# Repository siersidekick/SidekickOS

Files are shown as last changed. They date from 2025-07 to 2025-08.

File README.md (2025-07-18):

# SidekickOS - Open Source Smart Glasses

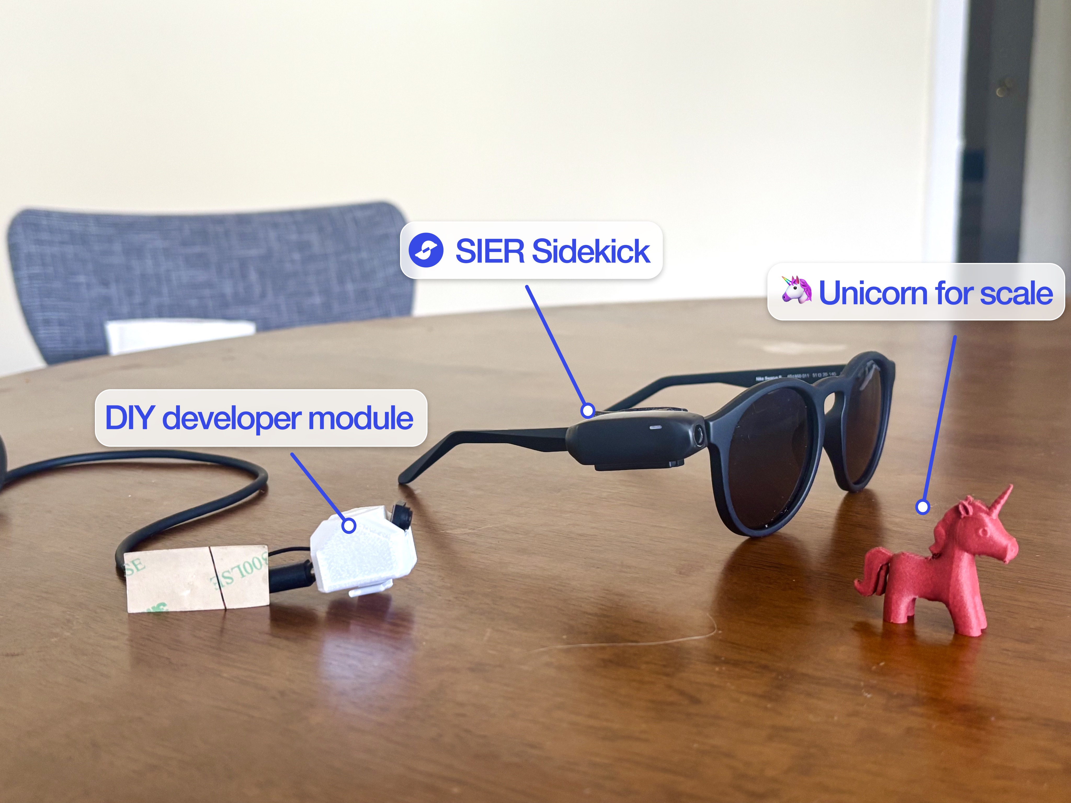
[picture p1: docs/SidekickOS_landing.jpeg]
SidekickOS Landing


An open-source implementation of smart glasses functionality, inspired by the [SIER Sidekick](https://siertech.com). Transform any glasses into smart glasses with camera capture, audio streaming, and AI assistance capabilities.






## 🎯 **What is SidekickOS?**

SidekickOS is an open-source smart glasses platform that provides:

- **📷 High-Resolution Camera Capture** - Up to 1600x1200 native
- **🎤 Audio Streaming** - G.711 μ-law encoded audio over BLE (Work in Progress)
- **📱 Multi-Platform Clients** - Python API and Web browser interface
- **⚡ Ultra-Performance** - Optimized BLE 5.0 with 517-byte MTU and Data Length Extension
- **🔧 Modular Design** - Separate firmware and client components
- **🌍 Cross-Platform** - Works on Mac, Windows, Linux, and mobile apps (React Native in development)

### **Developed with SIER Technologies**

This project is developed in collaboration with [SIER Technologies](https://siertech.com), makers of the Sidekick smart glasses:
- Turn any glasses into smart glasses
- Capture life with high-quality camera
- Voice-activated AI assistance (through client integration)
- Live streaming capabilities (through client apps)
- Hands-free operation

## 🚀 **Quick Start**

### **1. Hardware Setup**

**Required Hardware:**
- XIAO ESP32S3 Sense (with camera and microphone)
- USB-C cable for programming

**3D Printable Hardware:**
- **CAD Model**: [`hardware/SidekickOS-ESP32S3-v1.step`](hardware/SidekickOS-ESP32S3-v1.step) - Full 3D model for modifications
- **3D Print Files**: 
  - [`hardware/SidekickOS-ESP32S3-v1-print.stl`](hardware/SidekickOS-ESP32S3-v1-print.stl) - STL format
  - [`hardware/SidekickOS-ESP32S3-v1-print.3mf`](hardware/SidekickOS-ESP32S3-v1-print.3mf) - 3MF format (recommended)

**Hardware Renders:**
| Front View | Back View |
|---|---|
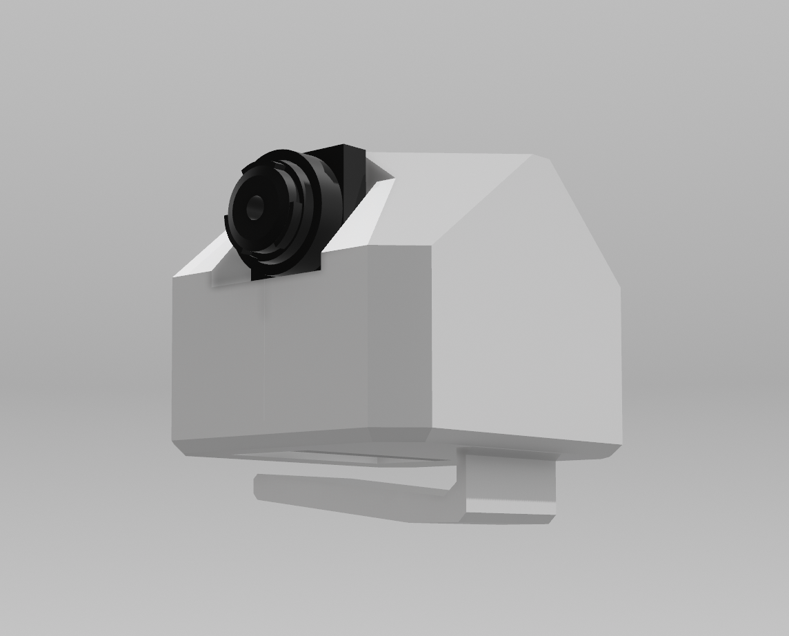
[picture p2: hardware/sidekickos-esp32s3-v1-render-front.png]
Front Render
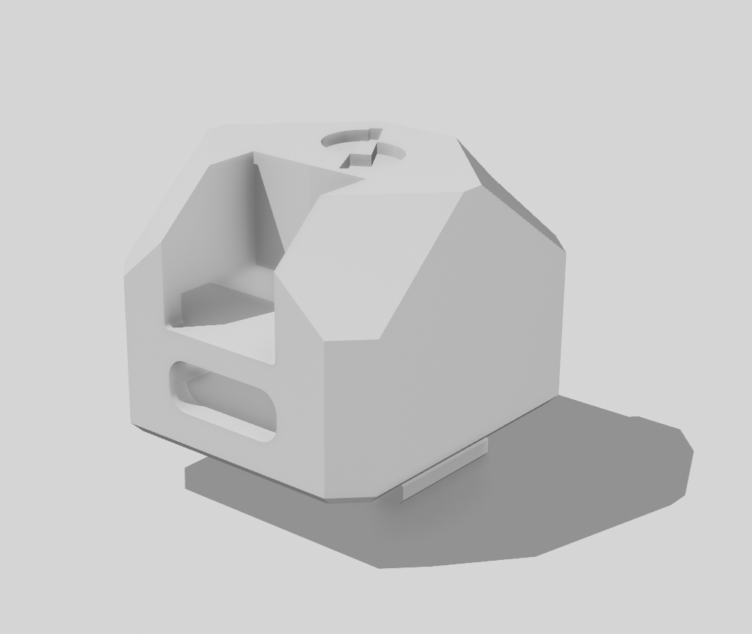
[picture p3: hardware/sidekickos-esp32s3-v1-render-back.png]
Back Render
|  |  |

**Note:** 3D printable mounting solution now available! See [`docs/hardware.md`](docs/hardware.md) for complete assembly instructions.

### **2. Firmware Installation**

```bash
# Clone the repository
git clone https://github.com/siersidekick/SidekickOS.git
cd sidekickos/firmware

# Install ESP-IDF (if not already installed)
# Follow: https://docs.espressif.com/projects/esp-idf/en/latest/esp32/get-started/

# Build and flash firmware
idf.py build
idf.py flash monitor
```

### **3. Client Setup**

**Python Client:**
```bash
cd sidekickos-client
pip install -e .
python demos/example_camera_usage.py
```

**Web Client:**
```bash
# Simply open demos/sidekickos-web-client.html in a modern desktop browser
# Requires Web Bluetooth API support (Chrome/Edge on desktop only)
# Note: iOS Safari and mobile browsers do not support Web Bluetooth
```

## 📱 **Client Applications**

### **Python Client (`sidekickos-client/`)**

**Features:**
- Full camera control and streaming
- High-resolution image capture (up to 1920x1080)
- Audio streaming and processing (Work in Progress)
- Performance monitoring
- Cross-platform (Mac, Windows, Linux)

**Usage:**
```python
from sidekickos import ESP32Camera

camera = ESP32Camera()
await camera.connect()
image = await camera.capture_image()
image.save("photo.jpg")
```

### **Web Client (`sidekickos-client/sidekickos-web-client.html`)**

**Features:**
- Browser-based interface (no installation required)
- Real-time camera streaming
- Audio streaming with Web Audio API (Work in Progress)
- Performance monitoring dashboard
- Desktop compatible (Chrome/Edge only, no iOS/mobile browser support)

**Usage:**
1. Open `sidekickos-client/sidekickos-web-client.html` in Chrome/Edge (desktop only)
2. Click "Connect to Camera"
3. Start capturing photos or streaming video

**Mobile App (React Native):**
- iOS and Android app in development
- Will provide full mobile BLE support
- Expected release: next few months

## 🔧 **Technical Specifications**

### **ESP32S3 Firmware**
- **Camera**: OV2640 sensor, JPEG compression
- **Audio**: PDM microphone, G.711 μ-law encoding
- **Connectivity**: BLE 5.0 with Data Length Extension
- **Performance**: 300+ kbps bandwidth, 30 FPS capability
- **Resolutions**: 96x96 to 1600x1200 native

### **BLE Protocol**
- **Service UUID**: `12345678-1234-1234-1234-123456789abc`
- **MTU**: Up to 517 bytes (BLE 5.0 DLE)
- **Chunk Size**: 510 bytes optimized
- **Audio**: 8kHz, 16-bit PCM → G.711 μ-law
- **Commands**: Quality, resolution, streaming control

### **Performance Metrics**
- **Image Transfer**: 200-400 kbps
- **Audio Streaming**: 12.8 kbps (Work in Progress)
- **Latency**: 1-3 seconds per frame
- **Range**: 10-30 meters
- **Battery Life**: Several hours (depends on usage and hardware configuration)

## 🎮 **Usage Examples**

### **Basic Photo Capture**
```python
# Python
import asyncio
from sidekickos import ESP32Camera

async def take_photo():
    camera = ESP32Camera()
    await camera.connect()
    
    # Set high quality
    await camera.set_quality(10)
    await camera.set_resolution(8)  # VGA
    
    # Capture image
    image = await camera.capture_image()
    image.save("my_photo.jpg")
    
    await camera.disconnect()

asyncio.run(take_photo())
```

### **Live Streaming**
```python
# Python streaming
def frame_callback(frame):
    print(f"Frame {frame.frame_number}: {frame.size} bytes")
    frame.save(f"frame_{frame.frame_number:04d}.jpg")

await camera.start_streaming(frame_callback, interval=0.5)
await asyncio.sleep(10)  # Stream for 10 seconds
await camera.stop_streaming()
```

### **🐕 Smart Dog Detection Demo**
```bash
cd sidekickos-client
pip install -e .
python demos/dog_detection/simple_dog_detector.py
```

## 🛠️ **Development**

### **Firmware Development**
```bash
cd firmware
idf.py menuconfig  # Configure project
idf.py build       # Build firmware
idf.py flash       # Flash to device
idf.py monitor     # View serial output
```

### **Client Development**
```bash
cd sidekickos-client
pip install -e .   # Install in development mode
python -m pytest   # Run tests (if available)
```

### **Adding New Features**

**Firmware Side:**
1. Add new BLE characteristics in `main/main.c`
2. Implement command handlers
3. Update protocol documentation

**Client Side:**
1. Extend `ESP32Camera` class in `sidekickos/__init__.py`
2. Add new methods and callbacks
3. Update examples and documentation

## 📊 **Performance Optimization**

### **For Maximum Quality**
- Use VGA (640x480) or higher resolution
- Set quality to 4-10 (lower = better)
- Use Python client for post-processing
- Enable image enhancement and upscaling

### **For Maximum Speed**
- Use QVGA (320x240) resolution
- Set quality to 25-30
- Use 1-2 second frame intervals
- Use Web client for real-time viewing

### **For Battery Life**
- Reduce frame rate (5+ second intervals)
- Lower resolution (QVGA or below)
- Disable audio streaming when not needed
- Use deep sleep between captures

## 🤝 **Contributing**

We welcome contributions! Please see [CONTRIBUTING.md](CONTRIBUTING.md) for guidelines.

**Areas for Contribution:**
- AI integration (ChatGPT, local models)
- Computer vision demos (expand beyond dog detection)
- React Native mobile app development
- Audio streaming improvements
- Performance optimizations
- Documentation improvements

## 🤖 **AI-Powered Demos**

### **🐕 Dog Detection Demo**
```bash
cd sidekickos-client
pip install -e .
python demos/dog_detection/simple_dog_detector.py
```

Detects dogs and saves photos to "cute dogs" folder.

📹 **[Watch Demo Video](https://drive.google.com/file/d/1LnD9ZVXxRB4CjpYO92vVTl6aJtVk8wdE/view?usp=sharing)** - See dog detection in action!

## 📄 **License**

This project is licensed under the MIT License - see the [LICENSE](LICENSE) file for details.

## 🙏 **Acknowledgments**

- Developed in collaboration with [SIER Technologies](https://siertech.com), makers of the Sidekick smart glasses
- Built on ESP-IDF framework and ESP32S3 platform
- Uses Seeed Studio XIAO ESP32S3 Sense hardware
- Community contributions and feedback

## 📚 **Documentation**

Comprehensive documentation is available in the `docs/` directory:

- **[📖 Documentation Index](docs/index.md)** - Complete documentation navigation
- **[Python Library Guide](docs/python-library.md)** - Complete Python client documentation
- **[Demo Scripts](docs/demos.md)** - Guide to all demo applications
- **[Firmware Guide](docs/firmware.md)** - ESP32S3 firmware documentation
- **[Hardware Setup](docs/hardware.md)** - Hardware compatibility and setup
- **[Contributing](CONTRIBUTING.md)** - Guidelines for contributors

## 📞 **Support**

- **Issues**: Open a GitHub issue for bugs or feature requests
- **Discussions**: Use GitHub Discussions for questions and ideas
- **Documentation**: See links above for detailed guides

## 🔮 **Roadmap**

**Current (v1.0):**
- ✅ Basic camera streaming
- ✅ Python and Web clients (desktop)
- ✅ High-resolution capture
- ✅ Performance optimization
- 🔄 Audio streaming (Work in Progress)

**Planned (v1.1):**
- 🔄 React Native mobile app (iOS/Android)
- 🔄 Complete audio streaming implementation
- 🔄 AI integration (ChatGPT, local models)
- 🔄 Voice activation ("Hey Sidekick")

**Future (v2.0):**
- 🔄 Live streaming to social platforms
- 🔄 Real-time object recognition
- 🔄 Augmented reality overlays
- 🔄 Advanced AI assistant features

---

**Turn any glasses into smart glasses with SidekickOS! 🤓✨**

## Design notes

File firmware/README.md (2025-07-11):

# SidekickOS ESP32S3 Firmware

This directory contains the ESP32S3 firmware for the SidekickOS smart glasses project.

## 🚀 **Quick Start**

```bash
# Install ESP-IDF (if not already installed)
# Follow: https://docs.espressif.com/projects/esp-idf/en/latest/esp32/get-started/

# Build and flash
idf.py build
idf.py flash monitor
```

## 📁 **Directory Structure**

```
firmware/
├── main/                   # Main application code
│   ├── main.c             # Primary firmware implementation
│   ├── CMakeLists.txt     # Main component build config
│   └── idf_component.yml  # Component dependencies
├── components/             # Custom components
│   └── posix_stub/        # POSIX compatibility layer
├── managed_components/     # ESP component dependencies
│   ├── espressif__esp32-camera/    # Camera driver
│   └── espressif__esp_h264/        # H.264 codec (future use)
├── CMakeLists.txt         # Project build configuration
├── dependencies.lock      # Dependency lock file
├── partitions.csv         # Flash partition table
├── sdkconfig*             # Build configuration files
└── README.md             # This file
```

## 🔧 **Features**

- **Camera**: OV2640 sensor with JPEG compression
- **Audio**: PDM microphone with G.711 μ-law encoding
- **BLE**: Optimized BLE 5.0 with 517-byte MTU
- **Performance**: 240MHz CPU, PSRAM optimization
- **Streaming**: Real-time image and audio streaming

## 📋 **Requirements**

- **Hardware**: XIAO ESP32S3 Sense
- **ESP-IDF**: Version 5.0 or later
- **Python**: Version 3.6 or later (for ESP-IDF)

## 🔨 **Build Instructions**

### **1. Setup ESP-IDF**
```bash
# Clone ESP-IDF
git clone -b v5.0 --recursive https://github.com/espressif/esp-idf.git
cd esp-idf
./install.sh
source export.sh
```

### **2. Build Firmware**
```bash
cd sidekickos/firmware

# Configure (optional - defaults are optimized)
idf.py menuconfig

# Build
idf.py build

# Flash and monitor
idf.py flash monitor
```

## ⚙️ **Configuration**

Key configuration options:

- **Target**: ESP32-S3
- **CPU Frequency**: 240MHz
- **Flash Size**: 8MB
- **PSRAM**: Enabled (Octal, 80MHz)
- **BLE**: Enabled with Data Length Extension
- **Camera**: ESP32-Camera component

## 📊 **Performance**

- **Image Streaming**: 200-400 kbps
- **Audio Streaming**: 12.8 kbps
- **Frame Rate**: Up to 30 FPS
- **Latency**: 1-3 seconds per frame
- **Range**: 10-30 meters

## 🔧 **Customization**

See [firmware documentation](../docs/firmware.md) for detailed customization instructions.

## 🐛 **Troubleshooting**

### **Common Issues**

| Problem | Solution |
|---|---|
| Build fails | Ensure ESP-IDF v5.0+ is installed and sourced |
| Camera not working | Check hardware connections, try lower resolution |
| BLE not visible | Verify BLE is enabled in menuconfig |
| Flash errors | Check USB connection, try different cable |

### **Debug Output**

```bash
# Monitor with filtering
idf.py monitor --print_filter="*:I ESP32S3_CAMERA:D"

# Save debug output
idf.py monitor | tee debug.log
```

## 📞 **Support**

- **Documentation**: See [../docs/firmware.md](../docs/firmware.md)
- **Issues**: Open GitHub issue with firmware tag
- **ESP-IDF Help**: [ESP-IDF Documentation](https://docs.espressif.com/projects/esp-idf/)

---

**Part of the SidekickOS open-source smart glasses project 🤓**

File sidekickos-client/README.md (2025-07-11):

# SidekickOS Python Library

This directory contains the SidekickOS Python library for ESP32S3 BLE camera interface.

## Quick Start

```bash
# Install the library
pip install -e .

# Run a demo
python demos/example_camera_usage.py
```

## 📚 Documentation

For complete documentation, please see:

- **[Python Library Guide](../docs/python-library.md)** - Complete API documentation
- **[Demo Scripts Guide](../docs/demos.md)** - Guide to all demo applications
- **[Main Project README](../README.md)** - Project overview and getting started

## Structure

```
sidekickos-client/
├── sidekickos/           # Main Python library
│   └── __init__.py        # ESP32Camera, ImageFrame classes
├── demos/                 # Example scripts
│   ├── example_camera_usage.py
│   └── dog_detection/
├── setup.py               # Installation configuration
└── requirements.txt       # Dependencies
```

## Quick Install & Test

```bash
pip install -e .
python -c "from sidekickos import ESP32Camera; print('✅ Installation successful!')"
```

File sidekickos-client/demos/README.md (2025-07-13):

# SidekickOS Demos

This directory contains various demonstration scripts and examples for the SidekickOS platform.

## 📁 **Available Demos**

### **🤖 Gemini Live Demo** (`gemini_live/`)
A smart glasses demo that integrates the SidekickOS BLE camera with Google's Gemini Live API for real-time computer vision and audio interaction.

**Features:**
- Real-time image capture from SidekickOS camera
- Voice interaction with Gemini AI
- Audio responses describing what the AI sees
- True smart glasses experience

**Setup:** See `gemini_live/GEMINI_DEMO_README.md`

### **🐕 Dog Detection Demo** (`dog_detection/`)
Computer vision demo for detecting dogs in camera feeds.

### **📷 Basic Camera Usage** (`example_camera_usage.py`)
Basic examples showing how to use the SidekickOS camera for image capture and streaming.

## 🚀 **Quick Start**

1. **Install base dependencies:**
   ```bash
   pip install -r requirements.txt
   ```

2. **Choose a demo:**
   - For Gemini Live: `cd gemini_live && python sidekickos_gemini_demo.py`
   - For basic camera: `python example_camera_usage.py`

3. **Make sure your SidekickOS device is powered on and nearby**

## 📋 **Requirements**

- SidekickOS device (powered on and in range)
- Python 3.8+
- Additional requirements per demo (see individual README files)

## 💡 **Creating New Demos**

To add a new demo:

1. Create a new subdirectory: `mkdir your_demo_name/`
2. Add your demo files
3. Include a README.md with setup instructions
4. Update this index file

## 🆘 **Need Help?**

- Check individual demo README files for specific setup instructions
- Ensure your SidekickOS device is properly configured
- Verify all dependencies are installed

---

**Happy coding with SidekickOS!** 🤖👓

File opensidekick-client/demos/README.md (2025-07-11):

# OpenSidekick Demo Scripts

This directory contains demonstration scripts for the OpenSidekick ESP32 camera system.

## Prerequisites

Install the opensidekick library:

```bash
cd ..
pip install -e .
```

Or install dependencies manually:

```bash
cd ..
pip install -r requirements.txt
```

## Demo Scripts

### Camera Examples

**example_camera_usage.py**
Basic camera usage examples: single image capture, video streaming, performance testing, interactive mode.

```bash
python example_camera_usage.py
```

**practical_high_res.py**
High-resolution image capture with intelligent upscaling to 1920x1080.

```bash
python practical_high_res.py
```

**opensidekick-web-client.html**
Web-based camera interface. Open in any web browser and follow instructions to connect.

### Dog Detection

Dog detection demos are in the `dog_detection/` folder:

**dog_detection/simple_dog_detector.py**
Streamlined dog detection. Saves clean images to "cute dogs" folder.

```bash
cd dog_detection
python simple_dog_detector.py
```

**dog_detection/dog_detector_demo.py**
Advanced dog detection with performance monitoring and statistics.

```bash
cd dog_detection
python dog_detector_demo.py
```

## Running Demos

1. Connect your ESP32 camera and make sure it's powered on
2. Navigate to the appropriate directory
3. Run the script

## Troubleshooting

- Import errors: Make sure you're running from the correct directory
- Camera connection issues: Ensure ESP32 is powered and Bluetooth is enabled
- Missing dependencies: Run `pip install -r ../requirements.txt`

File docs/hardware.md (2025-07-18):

# Hardware Guide - SidekickOS

## 🔧 **Required Hardware**

### **Primary Components**

#### **XIAO ESP32S3 Sense**
- **MCU**: ESP32-S3 dual-core processor @ 240MHz
- **Memory**: 8MB PSRAM, 8MB Flash
- **Camera**: OV2640 2MP camera sensor
- **Microphone**: PDM digital microphone
- **Connectivity**: WiFi 802.11 b/g/n, Bluetooth 5.0 BLE
- **Size**: 21×17.5mm (ultra-compact)
- **Power**: USB-C charging, 3.7V battery connector

**Purchase Links:**
- [Seeed Studio Official](https://www.seeedstudio.com/XIAO-ESP32S3-Sense-p-5639.html)
- [Amazon](https://amazon.com/dp/B0C69FFVHH)
- [Adafruit](https://www.adafruit.com/product/5426)

#### **Glasses Frame**
- Any standard eyeglasses frame

#### **3D Printable Mount**
- **📁 Hardware Files**: Available in [`../hardware/`](../hardware/) directory
- **🖨️ 3D Print Ready**: STL and 3MF files included
- **🔧 CAD Model**: STEP file for modifications
- **📸 Visual Reference**: Front and back render images

### **Optional Components**

#### **Battery Pack**
- **Capacity**: 100-500mAh recommended
- **Voltage**: 3.7V Li-Po battery
- **Size**: Small enough to fit in glasses arm or pocket

**Recommended Batteries:**
- Small form factor Li-Po batteries
- Capacity depends on use case and mounting solution

#### **Mounting Hardware**
- Mounting solutions currently in development
- Hardware assembly documentation coming soon

## 🔌 **Wiring and Connections**

**Note**: All pins are pre-configured in the firmware. No external wiring required for basic functionality.

## 🔋 **Power Management**

### **Power Consumption**
- **Idle**: ~50mA
- **Camera Active**: ~150-200mA
- **BLE Streaming**: ~200-250mA
- **Peak Usage**: ~300mA

### **Battery Life Estimates**
Battery life depends on:
- Camera resolution and quality settings
- Frame rate and streaming frequency
- Audio streaming usage (when implemented)
- BLE connection activity

Typical usage with optimized settings: 2-8 hours depending on battery capacity and usage patterns.

### **Power Optimization Tips**
- Use deep sleep between captures
- Reduce frame rate for longer battery life
- Lower camera resolution when possible
- Disable audio streaming when not needed

## 🏗️ **Mechanical Design**

### **3D Printable Mounting Solution**

**Available Hardware Files:**
- **CAD Model**: [`../hardware/SidekickOS-ESP32S3-v1.step`](../hardware/SidekickOS-ESP32S3-v1.step) - Full 3D model (STEP format)
- **3D Print Ready**: 
  - [`../hardware/SidekickOS-ESP32S3-v1-print.stl`](../hardware/SidekickOS-ESP32S3-v1-print.stl) - STL format
  - [`../hardware/SidekickOS-ESP32S3-v1-print.3mf`](../hardware/SidekickOS-ESP32S3-v1-print.3mf) - 3MF format (recommended)

**Hardware Renders:**
| Front View | Back View |
|---|---|
| Front Render | Back Render |

### **Mounting Features**

The SidekickOS ESP32S3 v1 mount includes:

- **Glasses Frame Integration**: Designed to clip onto standard eyeglass frames
- **Secure Camera Positioning**: Optimized positioning for the OV2640 camera sensor
- **ESP32S3 Housing**: Custom fit for the XIAO ESP32S3 Sense module
- **Access Ports**: USB-C port access for programming and charging

### **3D Printing Specifications**

**Recommended Settings:**
- **Layer Height**: 0.2mm
- **Infill**: 20-30%
- **Support**: Required for overhangs
- **Material**: PLA or PETG recommended
- **Print Orientation**: Follow 3MF file orientation

**Print Time**: Approximately 30 minutes to 1 hour depending on settings

## 📐 **Dimensions and Clearances**

### **XIAO ESP32S3 Sense Dimensions**
- Length: 21mm
- Width: 17.8mm
- Height: 15mm (with camera)
- Weight: ~5g

### **Mounting Clearances**
- Camera field of view: 66° diagonal
- Minimum clearance from lens: 15mm
- Recommended mounting height: 5-10mm above frame
- USB-C access: 10mm clearance needed

## 🔧 **Assembly Instructions**

### **3D Printing the Mount**

1. **Download Files**: Get the 3D print files from the [`../hardware/`](../hardware/) directory
2. **Print Settings**: Use the recommended settings above (0.2mm layer height, 20-30% infill)
3. **Support Material**: Enable supports for overhangs
4. **Post-Processing**: Remove supports and sand rough edges if needed

### **Hardware Assembly**

**Step 1: Prepare the ESP32S3**
1. Flash the SidekickOS firmware to your XIAO ESP32S3 Sense
2. Test basic functionality using the serial monitor
3. Verify camera and BLE functionality

**Step 2: Mount Assembly**
1. Carefully insert the ESP32S3 Sense into the 3D printed mount
2. Ensure the camera lens aligns with the mount opening
3. Verify USB-C port accessibility for charging/programming
4. Check that the mount securely holds the device

**Step 3: Glasses Integration**
1. Identify the best mounting position on your glasses frame
2. Clip or attach the mount to the glasses frame
3. Ensure the camera has an unobstructed view
4. Test comfort and stability during movement

**Step 4: Final Testing**
1. Connect via Python or Web client
2. Test camera capture and streaming
3. Verify comfortable fit during extended wear
4. Adjust mounting position if needed

### **Tools Required**
- 3D printer (or access to 3D printing service)
- Basic hand tools for post-processing
- Your favorite glasses frame
- XIAO ESP32S3 Sense module

## 🛡️ **Safety Considerations**

### **Electrical Safety**
- Use proper Li-Po battery handling procedures
- Avoid short circuits
- Monitor battery temperature during charging
- Use appropriate fuses if modifying power circuits

### **Mechanical Safety**
- Ensure secure mounting to prevent device falling
- Avoid sharp edges in 3D printed parts
- Test comfort during extended wear
- Consider impact resistance for active use

### **Privacy and Legal**
- Check local laws regarding recording devices
- Consider privacy implications of camera/microphone
- Add visible indicators when recording
- Respect others' privacy in public spaces

## 🔍 **Troubleshooting**

### **Common Hardware Issues**

| Problem | Possible Cause | Solution |
|---|---|---|
| Camera not working | Loose connection | Check camera ribbon cable |
| Poor image quality | Lens dirty/scratched | Clean lens, check for damage |
| Short battery life | High power consumption | Optimize firmware settings |
| BLE connection issues | Interference | Check for 2.4GHz interference |
| Charging problems | Faulty USB cable | Try different USB-C cable |

### **Hardware Testing**

```bash
# Flash test firmware
cd firmware
idf.py flash monitor

# Check hardware status in serial output
# Look for:
# - Camera initialization success
# - I2S/microphone setup
# - BLE advertising start
# - Memory allocation success
```

## 📞 **Hardware Support**

- **XIAO ESP32S3 Documentation**: [Seeed Studio Wiki](https://wiki.seeedstudio.com/xiao_esp32s3_getting_started/)
- **ESP32S3 Datasheet**: [Espressif Official](https://www.espressif.com/sites/default/files/documentation/esp32-s3_datasheet_en.pdf)
- **Hardware Issues**: Open GitHub issue with hardware tag
- **Community**: Join discussions for hardware modifications and improvements

---

**Ready to build your own smart glasses? Let's get started! 🤓🔧**

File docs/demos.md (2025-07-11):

# SidekickOS Demo Scripts

This directory contains demonstration scripts for the SidekickOS ESP32 camera system.

## Prerequisites

Install the sidekickos library:

```bash
cd ..
pip install -e .
```

Or install dependencies manually:

```bash
cd ..
pip install -r requirements.txt
```

## Demo Scripts

### Camera Examples

**example_camera_usage.py**
Basic camera usage examples: single image capture, video streaming, performance testing, interactive mode.

```bash
python example_camera_usage.py
```

**sidekickos-web-client.html**
Web-based camera interface. Open in any web browser and follow instructions to connect.

### Dog Detection

Dog detection demos are in the `dog_detection/` folder:

**dog_detection/simple_dog_detector.py**
Streamlined dog detection. Saves clean images to "cute dogs" folder.

```bash
cd dog_detection
python simple_dog_detector.py
```

**dog_detection/dog_detector_demo.py**
Advanced dog detection with performance monitoring and statistics.

```bash
cd dog_detection
python dog_detector_demo.py
```

### 🎥 Video Demo

**Dog Detection in Action**
Watch the SidekickOS dog detection demo in action:

📹 **[Dog Detection Demo Video](https://drive.google.com/file/d/1LnD9ZVXxRB4CjpYO92vVTl6aJtVk8wdE/view?usp=sharing)**

This video demonstrates:
- Real-time camera streaming from ESP32S3
- Live dog detection using YOLOv5
- Clean image saving without bounding boxes
- Performance monitoring and statistics
- Bluetooth LE connectivity in action

> **Note**: The video shows the `simple_dog_detector.py` script detecting dogs and automatically saving photos to the "cute dogs" folder.

## Running Demos

1. Connect your ESP32 camera and make sure it's powered on
2. Navigate to the appropriate directory
3. Run the script

## Troubleshooting

- Import errors: Make sure you're running from the correct directory
- Camera connection issues: Ensure ESP32 is powered and Bluetooth is enabled
- Missing dependencies: Run `pip install -r ../requirements.txt`

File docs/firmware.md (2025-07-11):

# Firmware Guide - SidekickOS ESP32S3

## 🚀 **Overview**

The SidekickOS firmware is built on ESP-IDF (Espressif IoT Development Framework) and provides:
- High-performance camera capture and streaming
- Optimized BLE 5.0 communication with 517-byte MTU
- Advanced power management and performance optimization
- Modular architecture for easy customization
(PDM microphone audio with G.711 μ-law encoding is WIP)

## 🏗️ **Architecture**

### **Core Components**

```
SidekickOS Firmware Architecture
┌─────────────────────────────────────────┐
│                main.c                   │
├─────────────────────────────────────────┤
│  ┌─────────────┐  ┌─────────────────┐  │
│  │   Camera    │  │      Audio      │  │
│  │   Module    │  │     Module      │  │
│  │             │  │                 │  │
│  │ • OV2640    │  │ • PDM Mic       │  │
│  │ • JPEG      │  │ • G.711 μ-law   │  │
│  │ • Streaming │  │ • I2S Driver    │  │
│  └─────────────┘  └─────────────────┘  │
├─────────────────────────────────────────┤
│              BLE Stack                  │
│  ┌─────────────────────────────────────┐│
│  │ • Service: Camera Control          ││
│  │ • Characteristics: Image, Audio    ││
│  │ • MTU: 517 bytes (BLE 5.0 DLE)     ││
│  │ • Chunk Protocol: 510-byte packets ││
│  └─────────────────────────────────────┘│
├─────────────────────────────────────────┤
│           Performance Layer             │
│  • CPU: 240MHz locked                  │
│  • Memory: PSRAM optimization          │
│  • Power: Aggressive connection params │
│  • Tasks: Dual-core task distribution  │
└─────────────────────────────────────────┘
```

### **Task Architecture**

| Task | Core | Priority | Stack Size | Function |
|---|---|---|---|---|
| Main Task | 0 | 1 | 8KB | System initialization, watchdog |
| Streaming Task | 1 | 10 | 16KB | Camera capture, image transmission |
| Audio Task | 0 | 9 | 8KB | Microphone capture, audio streaming |
| BLE Stack | 0 | 19 | System | BLE communication handling |

## 🔧 **Build System**

### **Prerequisites**

1. **ESP-IDF Installation**
```bash
# Install ESP-IDF v5.0 or later
git clone -b v5.0 --recursive https://github.com/espressif/esp-idf.git
cd esp-idf
./install.sh
source export.sh
```

2. **Hardware Setup**
- XIAO ESP32S3 Sense board
- USB-C cable for flashing
- Ensure camera and microphone are connected

### **Build Process**

```bash
# Navigate to firmware directory
cd sidekickos/firmware

# Configure project (optional - defaults are optimized)
idf.py menuconfig

# Build firmware
idf.py build

# Flash to device
idf.py flash

# Monitor serial output
idf.py monitor

# Combined flash and monitor
idf.py flash monitor
```

### **Build Configuration**

Key configuration options in `sdkconfig`:

```ini
# Performance Optimization
CONFIG_ESP32S3_SPIRAM_SUPPORT=y
CONFIG_SPIRAM_MODE_OCT=y
CONFIG_SPIRAM_SPEED_80M=y

# BLE Optimization
CONFIG_BT_BLE_DATA_LENGTH_EXTENSION=y
CONFIG_BT_GATT_MAX_MTU=517
CONFIG_BT_ACL_TX_BUF_NUM=12

# Compiler Optimization
CONFIG_COMPILER_OPTIMIZATION_PERF=y
CONFIG_COMPILER_OPTIMIZATION_ASSERTIONS_DISABLE=y

# Camera Configuration
CONFIG_CAMERA_CORE0=y
CONFIG_CAMERA_DMA_BUFFER_SIZE_MAX=32768
```

## 📡 **BLE Protocol**

### **Service Structure**

**Primary Service**: `12345678-1234-1234-1234-123456789abc`

| Characteristic | UUID | Properties | Description |
|---|---|---|---|
| Control | `87654321-4321-4321-4321-cba987654321` | Read/Write | Command interface |
| Status | `11111111-2222-3333-4444-555555555555` | Read/Notify | Device status |
| Image | `22222222-3333-4444-5555-666666666666` | Read/Notify | Single image capture |
| Frame | `44444444-5555-6666-7777-888888888888` | Read/Notify | Video streaming |
| Audio | `33333333-4444-5555-6666-777777777777` | Read/Notify | Audio streaming |

### **Command Protocol**

**Control Commands** (sent to Control characteristic):

| Command | Format | Description |
|---|---|---|
| Capture | `CAPTURE` | Take single photo |
| Start Streaming | `START_FRAMES` | Begin video streaming |
| Stop Streaming | `STOP_FRAMES` | End video streaming |
| Start Audio | `START_AUDIO` | Begin audio streaming |
| Stop Audio | `STOP_AUDIO` | End audio streaming |
| Set Quality | `QUALITY:N` | Set JPEG quality (4-63) |
| Set Resolution | `SIZE:N` | Set camera resolution (0-13) |
| Set Interval | `INTERVAL:F` | Set frame interval in seconds |
| Get Status | `STATUS` | Request device status |

### **Data Transmission Protocol**

**Image/Frame Transmission** (chunked protocol):

1. **Start Header** (7 bytes):
   ```
   [0x01][chunks_hi][chunks_lo][size_b0][size_b1][size_b2][size_b3]
   ```

2. **Data Chunks** (3 + data bytes):
   ```
   [0x02][chunk_idx_hi][chunk_idx_lo][...data...]
   ```

3. **End Marker** (3 bytes):
   ```
   [0x03][chunks_hi][chunks_lo]
   ```

**Audio Transmission** (direct):
- Raw G.711 μ-law encoded data
- 160 samples per packet (160 bytes)
- 10 packets per second (100ms intervals)

## 📷 **Camera System**

### **Supported Resolutions**

| Size ID | Resolution | Dimensions | Typical Use |
|---|---|---|---|
| 0 | 96x96 | 96×96 | Thumbnails |
| 1 | QQVGA | 160×120 | Low bandwidth |
| 5 | QVGA | 320×240 | Standard streaming |
| 8 | VGA | 640×480 | High quality |
| 9 | SVGA | 800×600 | Photo capture |
| 10 | XGA | 1024×768 | High resolution |
| 11 | HD | 1280×720 | HD capture |
| 12 | SXGA | 1280×1024 | Maximum quality |
| 13 | UXGA | 1600×1200 | Ultra high-res |

### **Camera Configuration**

```c
camera_config_t camera_config = {
    .pin_pwdn = -1,
    .pin_reset = -1,
    .pin_xclk = 10,
    .pin_sscb_sda = 40,
    .pin_sscb_scl = 39,
    .pin_d7 = 48,
    .pin_d6 = 11,
    .pin_d5 = 12,
    .pin_d4 = 14,
    .pin_d3 = 16,
    .pin_d2 = 18,
    .pin_d1 = 17,
    .pin_d0 = 15,
    .pin_vsync = 38,
    .pin_href = 47,
    .pin_pclk = 13,
    .xclk_freq_hz = 24000000,
    .pixel_format = PIXFORMAT_JPEG,
    .frame_size = FRAMESIZE_QVGA,
    .jpeg_quality = 12,
    .fb_count = 1,
    .grab_mode = CAMERA_GRAB_WHEN_EMPTY,
    .fb_location = CAMERA_FB_IN_PSRAM
};
```

## 🎤 **Audio System**

### **PDM Microphone Configuration**

```c
i2s_config_t i2s_config = {
    .mode = (I2S_MODE_MASTER | I2S_MODE_RX | I2S_MODE_PDM),
    .sample_rate = 8000,
    .bits_per_sample = I2S_BITS_PER_SAMPLE_16BIT,
    .channel_format = I2S_CHANNEL_FMT_ONLY_LEFT,
    .communication_format = I2S_COMM_FORMAT_STAND_I2S,
    .intr_alloc_flags = ESP_INTR_FLAG_LEVEL2,
    .dma_buf_count = 6,
    .dma_buf_len = 80,
    .use_apll = true,
    .tx_desc_auto_clear = false,
    .fixed_mclk = 0
};
```

### **G.711 μ-law Encoding**

The firmware implements G.711 μ-law compression:
- **Input**: 16-bit PCM samples at 8kHz
- **Output**: 8-bit μ-law compressed audio
- **Compression Ratio**: 2:1
- **Quality**: Telephone quality (suitable for voice)

```c
uint8_t linear_to_mulaw(int16_t pcm_val) {
    const uint16_t BIAS = 0x84;
    const uint16_t CLIP = 32635;
    
    uint8_t sign = (pcm_val < 0) ? 0x80 : 0;
    if (pcm_val < 0) pcm_val = -pcm_val;
    if (pcm_val > CLIP) pcm_val = CLIP;
    
    pcm_val += BIAS;
    int exponent = 7;
    for (int expMask = 0x4000; (pcm_val & expMask) == 0 && exponent > 0; expMask >>= 1) {
        exponent--;
    }
    
    int mantissa = (pcm_val >> ((exponent == 0) ? 4 : (exponent + 3))) & 0x0F;
    uint8_t ulaw = ~(sign | (exponent << 4) | mantissa);
    
    return ulaw;
}
```

## ⚡ **Performance Optimization**

### **CPU Optimization**

```c
void boost_cpu_performance(void) {
    esp_pm_config_t pm_config = {
        .max_freq_mhz = 240,
        .min_freq_mhz = 240,  // Lock to max frequency
        .light_sleep_enable = false
    };
    esp_pm_configure(&pm_config);
}
```

### **BLE Optimization**

```c
void optimize_ble_timing(void) {
    esp_ble_conn_update_params_t conn_params = {
        .min_int = 6,   // 7.5ms minimum interval
        .max_int = 6,   // 7.5ms maximum interval
        .latency = 0,   // No latency
        .timeout = 400  // 4 second timeout
    };
    esp_ble_gap_update_conn_params(&conn_params);
}
```

### **Memory Management**

- **PSRAM Usage**: Camera framebuffers stored in PSRAM
- **Heap Monitoring**: Continuous free heap monitoring
- **Buffer Management**: Optimized buffer allocation and deallocation
- **Stack Sizes**: Task stacks sized for peak usage

## 🔧 **Customization**

### **Adding New Commands**

1. **Define Command String**:
```c
#define NEW_COMMAND "MY_COMMAND"
```

2. **Add Handler in `handle_control_command()`**:
```c
else if (strcmp(command, NEW_COMMAND) == 0) {
    // Handle your command
    ESP_LOGI(TAG, "Processing new command");
    // Your implementation here
}
```

3. **Update Documentation**: Add command to protocol docs

### **Adding New BLE Characteristics**

1. **Define UUID**:
```c
#define NEW_CHAR_UUID "aaaaaaaa-bbbb-cccc-dddd-eeeeeeeeeeee"
```

2. **Add Characteristic Creation**:
```c
// In gatts_profile_a_event_handler, ESP_GATTS_ADD_CHAR_EVT case
esp_bt_uuid_t new_uuid;
new_uuid.len = ESP_UUID_LEN_128;
// Set UUID bytes...
esp_ble_gatts_add_char(service_handle, &new_uuid, permissions, properties, NULL, NULL);
```

3. **Handle Read/Write Events**: Add handlers in BLE event callbacks

### **Modifying Camera Settings**

```c
sensor_t* s = esp_camera_sensor_get();
if (s != NULL) {
    s->set_brightness(s, 0);     // -2 to 2
    s->set_contrast(s, 0);       // -2 to 2  
    s->set_saturation(s, 0);     // -2 to 2
    s->set_gainceiling(s, 0);    // 0 to 6
    s->set_whitebal(s, 1);       // 0 = disable, 1 = enable
    s->set_hmirror(s, 0);        // 0 = disable, 1 = enable
    s->set_vflip(s, 0);          // 0 = disable, 1 = enable
}
```

## 🐛 **Debugging**

### **Serial Output**

```bash
# Monitor with timestamp and filtering
idf.py monitor --print_filter="*:I ESP32S3_CAMERA:D"

# Save output to file
idf.py monitor | tee debug_output.log
```

### **Common Debug Points**

1. **Camera Initialization**:
```c
ESP_LOGI(TAG, "Camera init result: %s", esp_err_to_name(err));
```

2. **BLE Connection Status**:
```c
ESP_LOGI(TAG, "BLE connected: %s", ble_device_connected ? "true" : "false");
```

3. **Memory Usage**:
```c
ESP_LOGI(TAG, "Free heap: %zu bytes", heap_caps_get_free_size(MALLOC_CAP_8BIT));
```

4. **Performance Metrics**:
```c
ESP_LOGI(TAG, "Frame %lu: %zu bytes in %lu ms", frame_count, fb->len, capture_time);
```

### **Troubleshooting**

| Issue | Symptoms | Solution |
|---|---|---|
| Camera not working | "Camera init failed" error | Check hardware connections, try lower resolution |
| BLE not advertising | No device visible in scans | Check BLE initialization, verify UUID format |
| Poor performance | Low FPS, timeouts | Check CPU frequency, optimize task priorities |
| Memory issues | Heap allocation failures | Reduce buffer sizes, check for memory leaks |
| Audio problems | No audio data, crackling | Verify I2S pins, check PDM configuration |

## 📊 **Performance Metrics**

### **Typical Performance**

| Configuration | Image Size | Transfer Time | Throughput | FPS |
|---|---|---|---|-----|
| QVGA, Q=25 | ~8KB | 0.8s | 80 kbps | 1.25 |
| QVGA, Q=12 | ~15KB | 1.2s | 100 kbps | 0.83 |
| VGA, Q=25 | ~25KB | 2.0s | 100 kbps | 0.5 |
| VGA, Q=12 | ~45KB | 3.5s | 103 kbps | 0.29 |

### **Audio Performance**

- **Latency**: 100-200ms
- **Throughput**: 12.8 kbps (64 kbps PCM → 12.8 kbps μ-law)
- **Quality**: Telephone quality, suitable for voice
- **CPU Usage**: ~15% on audio core

## 🔄 **Updates and Versioning**

### **Firmware Updates**

```bash
# Check current version
idf.py monitor | grep "SidekickOS.*Starting"

# Update to latest
git pull origin main
cd firmware
idf.py build flash
```
---
Happy coding!

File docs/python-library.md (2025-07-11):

# SidekickOS Python Library

A Python library for interfacing with the SidekickOS camera system. This library provides cross-platform support for Mac, Windows, and Linux using the `bleak` library.

## Features

- 📷 **Single Image Capture** - Capture high-quality JPEG images
- 🎥 **Video Streaming** - Continuous frame streaming with customizable frame rates
- ⚡ **High Performance** - Optimized for 517-byte MTU and 510-byte chunks
- 📊 **Performance Monitoring** - Real-time bandwidth and FPS tracking
- 🔧 **Camera Control** - Adjust quality, resolution, and frame intervals
- 🖼️ **PIL Integration** - Easy image processing with Python Imaging Library
- 🌍 **Cross-Platform** - Works on Mac, Windows, and Linux

## Installation

### Install as Library (Recommended)

Install the sidekickos library directly:

```bash
pip install -e .
```

Or for development:

```bash
git clone https://github.com/henrywarren/SidekickOS.git
cd SidekickOS/sidekickos-client
pip install -e .
```

### Manual Installation

Install dependencies manually:

```bash
pip install bleak pillow opencv-python ultralytics torch
```

### System Requirements

- **Mac**: Built-in Bluetooth LE support
- **Windows**: Windows 10/11 with Bluetooth LE support  
- **Linux**: BlueZ stack (usually pre-installed)

## Quick Start

### Basic Usage

```python
import asyncio
from sidekickos import ESP32Camera

async def main():
    camera = ESP32Camera()
    
    # Connect to camera
    if await camera.connect():
        # Capture a single image
        image = await camera.capture_image()
        if image:
            image.save("my_photo.jpg")
            print(f"Image saved: {image.size} bytes")
        
        await camera.disconnect()

asyncio.run(main())
```

### Streaming Example

```python
import asyncio
from sidekickos import ESP32Camera

def frame_callback(frame):
    print(f"Frame {frame.frame_number}: {frame.size} bytes")
    frame.save(f"frame_{frame.frame_number:04d}.jpg")

async def stream_example():
    camera = ESP32Camera()
    
    if await camera.connect():
        # Start streaming at 2 FPS
        await camera.start_streaming(
            callback=frame_callback,
            interval=0.5,  # 0.5 seconds = 2 FPS
            quality=25
        )
        
        # Stream for 10 seconds
        await asyncio.sleep(10)
        await camera.stop_streaming()
        await camera.disconnect()

asyncio.run(stream_example())
```

## Running the Examples

The project includes a comprehensive example script:

```bash
python example_camera_usage.py
```

This provides:
1. **Single Image Capture** - High-quality photo capture
2. **Video Streaming** - Continuous frame capture with auto-save
3. **Performance Testing** - Benchmark different quality/speed settings
4. **Interactive Mode** - Real-time camera control

## API Reference

### ESP32Camera Class

#### Connection Methods
- `connect(device_address=None, timeout=10.0)` - Connect to camera
- `disconnect()` - Disconnect from camera
- `scan_for_device(timeout=10.0)` - Scan for ESP32S3 camera

#### Image Capture
- `capture_image(timeout=10.0)` - Capture single image
- `start_streaming(callback, interval=0.5, quality=25)` - Start streaming
- `stop_streaming()` - Stop streaming

#### Camera Control
- `set_quality(quality)` - Set JPEG quality (4-63, lower = better)
- `set_resolution(size_code)` - Set camera resolution
- `set_interval(interval)` - Set frame interval in seconds
- `send_command(command)` - Send raw command to ESP32

#### Performance
- `get_performance_stats()` - Get bandwidth/FPS statistics

### ImageFrame Class

#### Properties
- `data` - Raw JPEG image data (bytes)
- `size` - Image size in bytes
- `timestamp` - Capture timestamp
- `frame_number` - Sequential frame number
- `completion_rate` - Percentage of chunks received

#### Methods
- `save(filename)` - Save image to file
- `to_pil_image()` - Convert to PIL Image for processing

## Camera Settings

### Resolution Codes
- `1` - QQVGA (160×120) - Fastest
- `5` - QVGA (320×240) - **Recommended**
- `6` - CIF (400×296)
- `7` - HVGA (480×320)
- `8` - VGA (640×480) - Highest quality

### Quality Settings
- `4-10` - Highest quality (larger files)
- `15-25` - **Recommended range**
- `30-50` - Lower quality (smaller files)
- `51-63` - Lowest quality

### Frame Intervals
- `0.1s` - 10 FPS (very fast)
- `0.5s` - 2 FPS (**recommended**)
- `1.0s` - 1 FPS (conservative)
- `2.0s+` - Slow capture

## Performance Optimization

### For Maximum Speed
```python
await camera.set_quality(30)      # Lower quality
await camera.set_resolution(1)    # Smallest resolution
await camera.set_interval(0.2)    # 5 FPS
```

### For Maximum Quality
```python
await camera.set_quality(10)      # High quality
await camera.set_resolution(8)    # VGA resolution
await camera.set_interval(2.0)    # Slower capture
```

### For Balanced Performance
```python
await camera.set_quality(25)      # Balanced quality
await camera.set_resolution(5)    # QVGA resolution
await camera.set_interval(0.5)    # 2 FPS
```

## Troubleshooting

### Connection Issues
1. **Camera not found**: Ensure ESP32S3 is powered on and advertising
2. **Connection timeout**: Try increasing the timeout parameter
3. **Service not found**: Verify ESP32S3 firmware is running correctly

### Performance Issues
1. **Slow transfer**: Check BLE signal strength and reduce distance
2. **Dropped frames**: Increase frame interval or reduce quality
3. **Memory errors**: Reduce resolution or implement frame buffering

### Platform-Specific Issues

#### Mac
- Grant Bluetooth permissions to Terminal/Python
- Ensure Bluetooth is enabled in System Preferences

#### Windows
- Install latest Bluetooth drivers
- Enable Bluetooth in Windows Settings
- May require running as Administrator

#### Linux
- Ensure BlueZ is installed: `sudo apt install bluez`
- Add user to bluetooth group: `sudo usermod -a -G bluetooth $USER`

## Performance Expectations

With optimized settings (QVGA, quality 25, 2 FPS):
- **Bandwidth**: 200-400 kbps
- **Frame Size**: 8-15 KB per frame
- **Latency**: 1-3 seconds per frame
- **Range**: 10-30 meters (depending on environment)

## Integration Examples

### Save to Different Formats
```python
# Save as different formats using PIL
pil_image = frame.to_pil_image()
pil_image.save("image.png", "PNG")
pil_image.save("image.bmp", "BMP")
```

### Image Processing
```python
from PIL import ImageEnhance

# Enhance captured image
pil_image = frame.to_pil_image()
enhancer = ImageEnhance.Brightness(pil_image)
bright_image = enhancer.enhance(1.5)
bright_image.save("enhanced.jpg")
```

### Real-time Display
```python
import matplotlib.pyplot as plt

def display_callback(frame):
    pil_image = frame.to_pil_image()
    plt.imshow(pil_image)
    plt.title(f"Frame {frame.frame_number}")
    plt.pause(0.1)
```

## License

This project is part of the ESP32S3 BLE Camera system. See the main project documentation for license details.

## Support

For issues and questions:
1. Check the troubleshooting section above
2. Verify ESP32S3 firmware is working with the HTML client
3. Test BLE connectivity with other devices
4. Check Python and dependency versions

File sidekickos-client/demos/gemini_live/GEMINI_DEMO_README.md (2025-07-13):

# SidekickOS + Gemini Live Demo

A smart glasses demo that connects your SidekickOS BLE camera to Google's Gemini Live API for real-time computer vision and audio interaction.

## 🎯 **What This Demo Does**

- **Captures images** from your SidekickOS BLE camera
- **Streams audio** from your microphone
- **Sends both** to Google's Gemini Live API
- **Receives audio responses** from Gemini that describe what it sees
- **Creates a smart glasses experience** where AI can see and respond to your world

## 🚀 **Quick Start**

### **1. Install Dependencies**
```bash
pip install -r requirements_gemini.txt
```

### **2. Get Gemini API Key**
1. Go to [Google AI Studio](https://aistudio.google.com/app/apikey)
2. Create a new API key
3. Set it as an environment variable:
```bash
export GEMINI_API_KEY="your-api-key-here"
```

### **3. Prepare Your Hardware**
- Make sure your SidekickOS device is powered on
- Ensure it's in pairing/discoverable mode
- Have your microphone and speakers ready

### **4. Run the Demo**
```bash
cd demos/gemini_live
python sidekickos_gemini_demo.py
```

## 💡 **How to Use**

1. **Start the demo** - It will automatically connect to your SidekickOS camera
2. **Speak naturally** - Gemini will hear your voice and respond with audio
3. **Point your camera** - Gemini can see what your camera sees
4. **Ask questions** like:
   - "What do you see?"
   - "Describe what's in front of me"
   - "What color is this object?"
   - "Read this text to me"
5. **Type messages** in the console if needed
6. **Type 'q'** to quit

## 🎬 **Example Interactions**

- **You**: "What do you see?"
- **Gemini**: "I can see a cluttered desk with a laptop, some papers, and a coffee mug. The lighting appears to be natural daylight coming from the left."

- **You**: "What color is my shirt?"
- **Gemini**: "I can see you're wearing a blue shirt."

- **You**: "Read this text to me"
- **Gemini**: "I can see some text that says 'Hello World' on what appears to be a computer screen."

## 🔧 **Technical Details**

### **Camera Settings**
- **Resolution**: QVGA (320x240) for optimal performance
- **Quality**: 30 (good balance of quality and speed)
- **Capture Rate**: Every 2 seconds to avoid overwhelming the API

### **Audio Settings**
- **Input**: 16kHz mono PCM
- **Output**: 24kHz mono PCM
- **Voice**: Zephyr (configurable)

### **Gemini Configuration**
- **Model**: `gemini-2.5-flash-preview-native-audio-dialog`
- **Response**: Audio only (optimized for smart glasses)
- **Context Window**: 25.6K tokens with sliding window compression

## 🐛 **Troubleshooting**

### **Camera Connection Issues**
- Ensure your SidekickOS device is powered on and nearby
- Check that Bluetooth is enabled on your computer
- Try restarting the SidekickOS device

### **Audio Issues**
- Make sure your microphone permissions are granted
- Check your default audio devices
- Ensure speakers/headphones are connected

### **API Issues**
- Verify your `GEMINI_API_KEY` is set correctly
- Check your internet connection
- Ensure you have API quota available

### **Performance Issues**
- The demo captures frames every 2 seconds to balance performance
- You can adjust the frame rate in the code if needed
- Consider using a wired connection for better stability

## 🎨 **Customization**

You can modify the demo by:
- Changing the camera resolution: `await self.camera.set_resolution(1-8)`
- Adjusting frame capture rate: Change `await asyncio.sleep(2.0)` in `get_frames()`
- Modifying the AI voice: Change `voice_name` in the config
- Adding custom system prompts: Edit the `initial_context` message

## 📝 **Notes**

- This demo requires a stable internet connection
- Gemini Live API usage counts against your API quota
- The camera captures are optimized for real-time processing
- Audio responses are generated in real-time by Gemini

## 🚨 **Privacy Notice**

This demo sends camera images and audio to Google's Gemini Live API. Make sure you're comfortable with this before running the demo. Images and audio are processed by Google's servers.

---

**Enjoy your smart glasses experience with SidekickOS + Gemini Live!** 🤖👓

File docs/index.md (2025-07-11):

# SidekickOS Documentation

Welcome to the SidekickOS documentation! This directory contains comprehensive guides for all aspects of the SidekickOS smart glasses platform.

## 📖 Documentation Index

### Getting Started
- **[Main README](../README.md)** - Project overview, quick start, and basic usage
- **[Contributing Guide](../CONTRIBUTING.md)** - How to contribute to the project

### Hardware & Firmware
- **[Hardware Setup](hardware.md)** - Hardware compatibility, mounting, and assembly
- **[Firmware Guide](firmware.md)** - ESP32S3 firmware installation and development

### Software & Development
- **[Python Library](python-library.md)** - Complete Python client API documentation
- **[Demo Scripts](demos.md)** - Guide to example applications and demos

## 🚀 Quick Navigation

### For Users
1. **New to SidekickOS?** → Start with [Main README](../README.md)
2. **Need hardware help?** → See [Hardware Setup](hardware.md)
3. **Want to use Python?** → Check [Python Library](python-library.md)
4. **Looking for examples?** → Browse [Demo Scripts](demos.md)

### For Developers
1. **Contributing code?** → Read [Contributing Guide](../CONTRIBUTING.md)
2. **Firmware development?** → See [Firmware Guide](firmware.md)
3. **Client development?** → Check [Python Library](python-library.md)
4. **Need examples?** → Browse [Demo Scripts](demos.md)

## 📁 Documentation Structure

```
docs/
├── index.md            # This file - documentation navigation
├── hardware.md         # Hardware setup and compatibility
├── firmware.md         # ESP32S3 firmware documentation
├── python-library.md   # Python client API documentation
└── demos.md           # Demo applications guide
```

## 💡 Need Help?

- **Can't find what you're looking for?** Check the [Main README](../README.md)
- **Found an issue?** Open a GitHub issue
- **Have questions?** Use GitHub Discussions
- **Want to contribute?** See [Contributing Guide](../CONTRIBUTING.md)

---

**Turn any glasses into smart glasses with SidekickOS! 🤓✨**

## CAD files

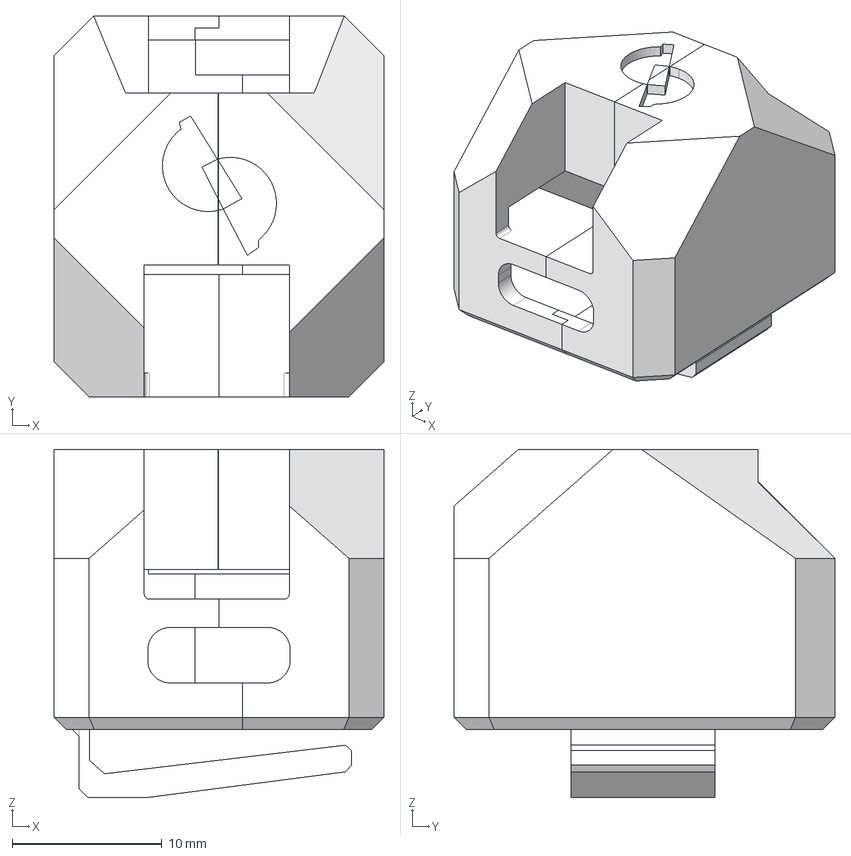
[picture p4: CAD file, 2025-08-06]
hardware/SidekickOS-ESP32S3-v1.step
22.0 x 25.5 x 23.3 mm
Imported
Xiao Sense Case v48 - PETG.stp

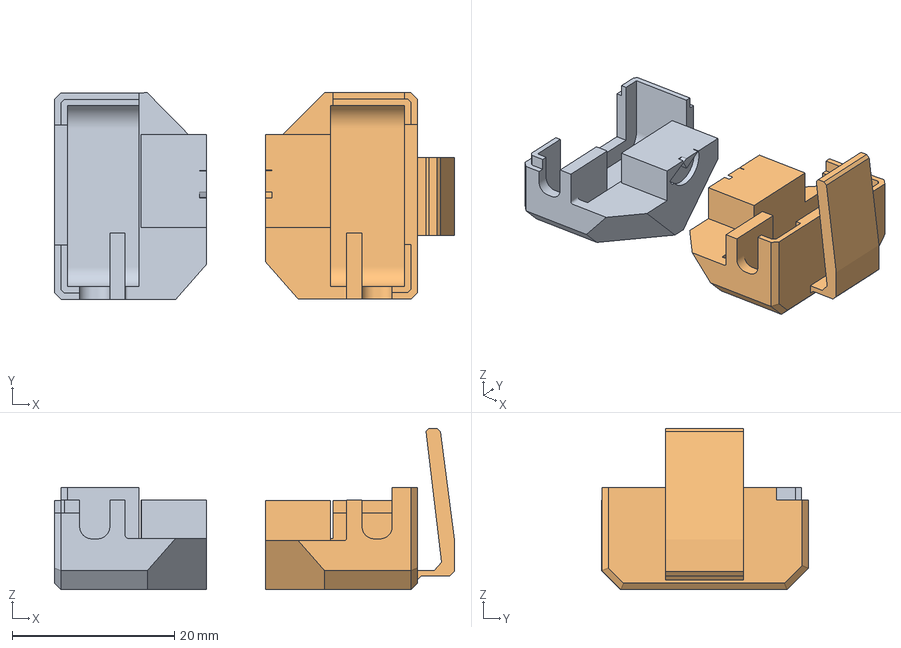
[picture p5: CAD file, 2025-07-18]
hardware/SidekickOS-ESP32S3-v1-print.3mf
49.3 x 25.5 x 19.9 mm
SidekickOS-ESP32S3-v1
Sub-merged body

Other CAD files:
hardware/SidekickOS-ESP32S3-v1-print.stl

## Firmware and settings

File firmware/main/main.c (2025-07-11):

#include <stdio.h>
#include <stdlib.h>
#include <string.h>
#include <math.h>
#include <inttypes.h>
#include "freertos/FreeRTOS.h"
#include "freertos/task.h"
#include "freertos/semphr.h"
#include "esp_system.h"
#include "esp_log.h"
#include "esp_camera.h"
#include "esp_timer.h"
#include "esp_spiffs.h"
#include "esp_task_wdt.h"
#include "nvs_flash.h"
#include "esp_bt.h"
#include "esp_bt_main.h"
#include "esp_gap_ble_api.h"
#include "esp_gatts_api.h"
#include "esp_bt_defs.h"
#include "esp_gatt_common_api.h"
#include "esp_psram.h"
#include "esp_heap_caps.h"
#include "posix_stub.h"
#include "driver/i2s.h"
#include "driver/gpio.h"
#include "esp_pm.h"

static const char *TAG = "ESP32S3_CAMERA";

// Camera pin definitions for XIAO ESP32S3 Sense
#define PWDN_GPIO_NUM     -1
#define RESET_GPIO_NUM    -1
#define XCLK_GPIO_NUM     10
#define SIOD_GPIO_NUM     40
#define SIOC_GPIO_NUM     39

#define Y9_GPIO_NUM       48
#define Y8_GPIO_NUM       11
#define Y7_GPIO_NUM       12
#define Y6_GPIO_NUM       14
#define Y5_GPIO_NUM       16
#define Y4_GPIO_NUM       18
#define Y3_GPIO_NUM       17
#define Y2_GPIO_NUM       15
#define VSYNC_GPIO_NUM    38
#define HREF_GPIO_NUM     47
#define PCLK_GPIO_NUM     13

#define LED_GPIO_NUM      21

// Microphone I2S pins - from Seeed Studio documentation
#define I2S_WS_PIN        42  // Serial clock (BCK)
#define I2S_SD_PIN        41  // Serial data in
#define I2S_PORT          I2S_NUM_0
#define I2S_SAMPLE_RATE   8000   // 8kHz sample rate like reference (telephony standard)
#define I2S_SAMPLE_BITS   16
#define I2S_CHANNELS      1
#define FRAME_SIZE        160    // 160 samples for 8kHz, 20ms frames (standard for telephony)

// BLE Configuration - Match HTML client exactly
#define BLE_SERVICE_UUID           "12345678-1234-1234-1234-123456789abc"
#define CONTROL_CHAR_UUID          "87654321-4321-4321-4321-cba987654321"
#define STATUS_CHAR_UUID           "11111111-2222-3333-4444-555555555555"
#define IMAGE_CHAR_UUID            "22222222-3333-4444-5555-666666666666"
#define FRAME_CONTROL_CHAR_UUID    "44444444-5555-6666-7777-888888888888"
#define AUDIO_CHAR_UUID            "33333333-4444-5555-6666-777777777777"


#define GATTS_NUM_HANDLE_TEST_A     20
#define TEST_DEVICE_NAME            "SidekickOS"

// Global variables
static bool ble_device_connected = false;
static bool frame_streaming_enabled = false;
static bool audio_streaming_enabled = false;
static bool capture_image_requested = false;  // Flag for async image capture
static float frame_interval = 0.033f;  // 33ms = 30 FPS (aggressive)
static int image_quality = 25;
static framesize_t current_frame_size = FRAMESIZE_QVGA;

// Audio variables
#define AUDIO_BUFFER_SIZE FRAME_SIZE  // Use frame size like reference
static int16_t* audio_buffer = NULL;
static uint8_t* mulaw_buffer = NULL;  // Buffer for μ-law encoded audio
static bool audio_initialized = false;
static bool i2s_driver_installed = false;

// Add timeout variables near other static variables
static uint32_t last_activity_time = 0;
static const uint32_t CONNECTION_TIMEOUT_MS = 30000; // 30 seconds timeout

// G.711 μ-law encoding functions
// Convert 16-bit linear PCM to 8-bit μ-law (based on reference implementation)
static uint8_t linear_to_mulaw(int16_t pcm_val) {
    const uint16_t BIAS = 0x84;
    const uint16_t CLIP = 32635;
    
    uint8_t sign = (pcm_val < 0) ? 0x80 : 0;
    if (pcm_val < 0) pcm_val = -pcm_val;
    if (pcm_val > CLIP) pcm_val = CLIP;
    
    pcm_val += BIAS;
    int exponent = 7;
    for (int expMask = 0x4000; (pcm_val & expMask) == 0 && exponent > 0; expMask >>= 1) {
        exponent--;
    }
    
    int mantissa = (pcm_val >> ((exponent == 0) ? 4 : (exponent + 3))) & 0x0F;
    uint8_t ulaw = ~(sign | (exponent << 4) | mantissa);
    
    return ulaw;
}

// Task handles
static TaskHandle_t streaming_task_handle = NULL;
static TaskHandle_t audio_task_handle = NULL;

// Semaphores
static SemaphoreHandle_t camera_mutex;

// BLE related variables
static uint16_t gatts_if;
static uint16_t conn_id;
static uint16_t control_handle;
static uint16_t status_handle;
static uint16_t image_handle;
static uint16_t frame_handle;
static uint16_t audio_handle;

#define PROFILE_NUM 1
#define PROFILE_A_APP_ID 0

// Struct definition for BLE profile instance - must be before array declaration
struct gatts_profile_inst {
    esp_gatts_cb_t gatts_cb;
    uint16_t gatts_if;
    uint16_t app_id;
    uint16_t conn_id;
    uint16_t service_handle;
    esp_gatt_srvc_id_t service_id;
    uint16_t char_handle;
    esp_bt_uuid_t char_uuid;
    esp_gatt_perm_t perm;
    esp_gatt_char_prop_t property;
    uint16_t descr_handle;
    esp_bt_uuid_t descr_uuid;
};

// Function declarations - moved before struct initialization
static void handle_control_command(const char* command);
static void send_ble_status(void);
static void gatts_profile_a_event_handler(esp_gatts_cb_event_t event, esp_gatt_if_t gatts_if_param, esp_ble_gatts_cb_param_t *param);
static void gatts_event_handler(esp_gatts_cb_event_t event, esp_gatt_if_t gatts_if, esp_ble_gatts_cb_param_t *param);
static void gap_event_handler(esp_gap_ble_cb_event_t event, esp_ble_gap_cb_param_t *param);
static void init_microphone(void);
static void audio_task(void *pvParameters);
static void send_audio_data(void);
static void boost_cpu_performance(void);
static void optimize_ble_timing(void);

// Add cleanup function declaration near other function declarations
static void cleanup_on_disconnect(void);
static void check_connection_timeout(void);

static struct gatts_profile_inst gl_profile_tab[PROFILE_NUM] = {
    [PROFILE_A_APP_ID] = {
        .gatts_cb = gatts_profile_a_event_handler,
        .gatts_if = ESP_GATT_IF_NONE,
    },
};

static esp_ble_adv_data_t adv_data = {
    .set_scan_rsp = false,
    .include_name = true,
    .include_txpower = false,
    .min_interval = 0x0020,
    .max_interval = 0x0040,
    .appearance = 0x00,
    .manufacturer_len = 0,
    .p_manufacturer_data = NULL,
    .service_data_len = 0,
    .p_service_data = NULL,
    .service_uuid_len = 0,  // Disable service UUID in advertising - let scan response handle it
    .p_service_uuid = NULL,
    .flag = (ESP_BLE_ADV_FLAG_GEN_DISC | ESP_BLE_ADV_FLAG_BREDR_NOT_SPT),
};

static esp_ble_adv_params_t adv_params = {
    .adv_int_min        = 0x20,
    .adv_int_max        = 0x40,
    .adv_type           = ADV_TYPE_IND,
    .own_addr_type      = BLE_ADDR_TYPE_PUBLIC,
    .channel_map        = ADV_CHNL_ALL,
    .adv_filter_policy = ADV_FILTER_ALLOW_SCAN_ANY_CON_ANY,
};

static void gatts_profile_a_event_handler(esp_gatts_cb_event_t event, esp_gatt_if_t gatts_if_param, esp_ble_gatts_cb_param_t *param) 
{
    switch (event) {
    case ESP_GATTS_REG_EVT:
        ESP_LOGI(TAG, "REGISTER_APP_EVT, status %d, app_id %d", param->reg.status, param->reg.app_id);
        
        // TEMPORARY: Use 16-bit UUID for testing - much more reliable for discovery
        gl_profile_tab[PROFILE_A_APP_ID].service_id.is_primary = true;
        gl_profile_tab[PROFILE_A_APP_ID].service_id.id.inst_id = 0x00;
        gl_profile_tab[PROFILE_A_APP_ID].service_id.id.uuid.len = ESP_UUID_LEN_16;
        gl_profile_tab[PROFILE_A_APP_ID].service_id.id.uuid.uuid.uuid16 = 0x1234;

        esp_err_t set_dev_name_ret = esp_ble_gap_set_device_name(TEST_DEVICE_NAME);
        if (set_dev_name_ret){
            ESP_LOGE(TAG, "set device name failed, error code = %x", set_dev_name_ret);
        }
        
        esp_err_t ret = esp_ble_gap_config_adv_data(&adv_data);
        if (ret){
            ESP_LOGE(TAG, "config adv data failed, error code = %x", ret);
        }
        
        esp_ble_gatts_create_service(gatts_if_param, &gl_profile_tab[PROFILE_A_APP_ID].service_id, GATTS_NUM_HANDLE_TEST_A);
        break;
        
    case ESP_GATTS_CREATE_EVT:
        ESP_LOGI(TAG, "CREATE_SERVICE_EVT, status %d, service_handle %d", param->create.status, param->create.service_handle);
        gl_profile_tab[PROFILE_A_APP_ID].service_handle = param->create.service_handle;
        
        // Log the service UUID being created
        ESP_LOGI(TAG, "Service created with UUID: %s", BLE_SERVICE_UUID);
        ESP_LOGI(TAG, "Service handle: %d", param->create.service_handle);
        
        esp_err_t start_ret = esp_ble_gatts_start_service(gl_profile_tab[PROFILE_A_APP_ID].service_handle);
        if (start_ret == ESP_OK) {
            ESP_LOGI(TAG, "Service started successfully");
        } else {
            ESP_LOGE(TAG, "Failed to start service: %s", esp_err_to_name(start_ret));
        }
        
        // Create control characteristic (128-bit UUID)
        esp_bt_uuid_t control_uuid;
        control_uuid.len = ESP_UUID_LEN_128;
        // UUID: 87654321-4321-4321-4321-cba987654321 (little-endian byte order)
        uint8_t control_uuid_128[16] = {
            0x21, 0x43, 0x65, 0x87, 0xa9, 0xcb, 0x21, 0x43,
            0x21, 0x43, 0x21, 0x43, 0x21, 0x43, 0x65, 0x87
        };
        memcpy(control_uuid.uuid.uuid128, control_uuid_128, 16);
        
        esp_ble_gatts_add_char(gl_profile_tab[PROFILE_A_APP_ID].service_handle, &control_uuid,
                              ESP_GATT_PERM_READ | ESP_GATT_PERM_WRITE,
                              ESP_GATT_CHAR_PROP_BIT_READ | ESP_GATT_CHAR_PROP_BIT_WRITE,
                              NULL, NULL);
        
        ESP_LOGI(TAG, "Control characteristic creation initiated");
        break;
        
    case ESP_GATTS_START_EVT:
        ESP_LOGI(TAG, "SERVICE_START_EVT, status %d, service_handle %d", param->start.status, param->start.service_handle);
        if (param->start.status == ESP_GATT_OK) {
            ESP_LOGI(TAG, "✅ BLE Service is now ACTIVE and discoverable!");
            ESP_LOGI(TAG, "Service UUID: %s", BLE_SERVICE_UUID);
            ESP_LOGI(TAG, "Device name: %s", TEST_DEVICE_NAME);
        } else {
            ESP_LOGE(TAG, "❌ Failed to start BLE service");
        }
        break;
        
    case ESP_GATTS_ADD_CHAR_EVT:
        ESP_LOGI(TAG, "ADD_CHAR_EVT, status %d, attr_handle %d, service_handle %d",
                param->add_char.status, param->add_char.attr_handle, param->add_char.service_handle);
        
        // Store the first characteristic handle as control handle
        static int char_count = 0;
        char_count++;
        
        if (char_count == 1) {
        control_handle = param->add_char.attr_handle;
            ESP_LOGI(TAG, "Control characteristic added, handle: %d", control_handle);
            
            // Add status characteristic (128-bit UUID)
            esp_bt_uuid_t status_uuid;
            status_uuid.len = ESP_UUID_LEN_128;
            // UUID: 11111111-2222-3333-4444-555555555555 (little-endian byte order)
            uint8_t status_uuid_128[16] = {
                0x55, 0x55, 0x55, 0x55, 0x55, 0x55, 0x44, 0x44,
                0x33, 0x33, 0x22, 0x22, 0x11, 0x11, 0x11, 0x11
            };
            memcpy(status_uuid.uuid.uuid128, status_uuid_128, 16);
            
            esp_ble_gatts_add_char(gl_profile_tab[PROFILE_A_APP_ID].service_handle, &status_uuid,
                                  ESP_GATT_PERM_READ,
                                  ESP_GATT_CHAR_PROP_BIT_READ | ESP_GATT_CHAR_PROP_BIT_NOTIFY,
                                  NULL, NULL);
            
            // Add descriptor immediately for status characteristic
            esp_bt_uuid_t status_descr_uuid;
            status_descr_uuid.len = ESP_UUID_LEN_16;
            status_descr_uuid.uuid.uuid16 = ESP_GATT_UUID_CHAR_CLIENT_CONFIG;
            esp_ble_gatts_add_char_descr(gl_profile_tab[PROFILE_A_APP_ID].service_handle, &status_descr_uuid,
                                        ESP_GATT_PERM_READ | ESP_GATT_PERM_WRITE, NULL, NULL);
        }
        else if (char_count == 2) {
            status_handle = param->add_char.attr_handle;
            ESP_LOGI(TAG, "Status characteristic added, handle: %d", status_handle);
            
            // Add image characteristic (128-bit UUID)
            esp_bt_uuid_t image_uuid;
            image_uuid.len = ESP_UUID_LEN_128;
            // UUID: 22222222-3333-4444-5555-666666666666 (little-endian byte order)
            uint8_t image_uuid_128[16] = {
                0x66, 0x66, 0x66, 0x66, 0x66, 0x66, 0x55, 0x55,
                0x44, 0x44, 0x33, 0x33, 0x22, 0x22, 0x22, 0x22
            };
            memcpy(image_uuid.uuid.uuid128, image_uuid_128, 16);
            
            esp_ble_gatts_add_char(gl_profile_tab[PROFILE_A_APP_ID].service_handle, &image_uuid,
                                  ESP_GATT_PERM_READ,
                                  ESP_GATT_CHAR_PROP_BIT_READ | ESP_GATT_CHAR_PROP_BIT_NOTIFY,
                                  NULL, NULL);
            
            // Add descriptor immediately for image characteristic
            esp_bt_uuid_t image_descr_uuid;
            image_descr_uuid.len = ESP_UUID_LEN_16;
            image_descr_uuid.uuid.uuid16 = ESP_GATT_UUID_CHAR_CLIENT_CONFIG;
            esp_ble_gatts_add_char_descr(gl_profile_tab[PROFILE_A_APP_ID].service_handle, &image_descr_uuid,
                                        ESP_GATT_PERM_READ | ESP_GATT_PERM_WRITE, NULL, NULL);
        }
        else if (char_count == 3) {
            image_handle = param->add_char.attr_handle;
            ESP_LOGI(TAG, "Image characteristic added, handle: %d", image_handle);
            
            // Add frame control characteristic (128-bit UUID)
            esp_bt_uuid_t frame_uuid;
            frame_uuid.len = ESP_UUID_LEN_128;
            // UUID: 44444444-5555-6666-7777-888888888888 (little-endian byte order)
            uint8_t frame_uuid_128[16] = {
                0x88, 0x88, 0x88, 0x88, 0x88, 0x88, 0x77, 0x77,
                0x66, 0x66, 0x55, 0x55, 0x44, 0x44, 0x44, 0x44
            };
            memcpy(frame_uuid.uuid.uuid128, frame_uuid_128, 16);
            
            esp_ble_gatts_add_char(gl_profile_tab[PROFILE_A_APP_ID].service_handle, &frame_uuid,
                                  ESP_GATT_PERM_READ,
                                  ESP_GATT_CHAR_PROP_BIT_READ | ESP_GATT_CHAR_PROP_BIT_NOTIFY,
                                  NULL, NULL);
            
            // Add descriptor immediately for frame characteristic
            esp_bt_uuid_t frame_descr_uuid;
            frame_descr_uuid.len = ESP_UUID_LEN_16;
            frame_descr_uuid.uuid.uuid16 = ESP_GATT_UUID_CHAR_CLIENT_CONFIG;
            esp_ble_gatts_add_char_descr(gl_profile_tab[PROFILE_A_APP_ID].service_handle, &frame_descr_uuid,
                                        ESP_GATT_PERM_READ | ESP_GATT_PERM_WRITE, NULL, NULL);
        }
        else if (char_count == 4) {
            frame_handle = param->add_char.attr_handle;
            ESP_LOGI(TAG, "Frame control characteristic added, handle: %d", frame_handle);
            
            // Add audio characteristic (128-bit UUID)
            esp_bt_uuid_t audio_uuid;
            audio_uuid.len = ESP_UUID_LEN_128;
            // UUID: 33333333-4444-5555-6666-777777777777 (little-endian byte order)
            uint8_t audio_uuid_128[16] = {
                0x77, 0x77, 0x77, 0x77, 0x77, 0x77, 0x66, 0x66,
                0x55, 0x55, 0x44, 0x44, 0x33, 0x33, 0x33, 0x33
            };
            memcpy(audio_uuid.uuid.uuid128, audio_uuid_128, 16);
            
            esp_ble_gatts_add_char(gl_profile_tab[PROFILE_A_APP_ID].service_handle, &audio_uuid,
                                  ESP_GATT_PERM_READ,
                                  ESP_GATT_CHAR_PROP_BIT_READ | ESP_GATT_CHAR_PROP_BIT_NOTIFY,
                                  NULL, NULL);
            
            // Add descriptor immediately for audio characteristic
            esp_bt_uuid_t audio_descr_uuid;
            audio_descr_uuid.len = ESP_UUID_LEN_16;
            audio_descr_uuid.uuid.uuid16 = ESP_GATT_UUID_CHAR_CLIENT_CONFIG;
            esp_ble_gatts_add_char_descr(gl_profile_tab[PROFILE_A_APP_ID].service_handle, &audio_descr_uuid,
                                        ESP_GATT_PERM_READ | ESP_GATT_PERM_WRITE, NULL, NULL);
        }
        else if (char_count == 5) {
            audio_handle = param->add_char.attr_handle;
            ESP_LOGI(TAG, "Audio characteristic added, handle: %d", audio_handle);
            ESP_LOGI(TAG, "All BLE characteristics created successfully!");
        }
        
        // Descriptors are now added immediately after each characteristic
        break;
        
    case ESP_GATTS_ADD_CHAR_DESCR_EVT:
        ESP_LOGI(TAG, "ADD_DESCR_EVT, status %d, attr_handle %d, service_handle %d",
                param->add_char_descr.status, param->add_char_descr.attr_handle, param->add_char_descr.service_handle);
        break;
        
    case ESP_GATTS_WRITE_EVT:
        ESP_LOGI(TAG, "GATT_WRITE_EVT, conn_id %d, trans_id %d, handle %d", 
                 (int)param->write.conn_id, (int)param->write.trans_id, (int)param->write.handle);
        
        // Update activity timer on any write
        last_activity_time = xTaskGetTickCount() * portTICK_PERIOD_MS;
        
        if (!param->write.is_prep) {
            ESP_LOGI(TAG, "GATT_WRITE_EVT, value len %d", param->write.len);
            
            // Handle control commands
            if (param->write.handle == control_handle) {
                char command[256];
                memcpy(command, param->write.value, param->write.len);
                command[param->write.len] = '\0';
                handle_control_command(command);
                
                // Small delay to ensure command processing completes before response
                vTaskDelay(pdMS_TO_TICKS(5));
            }
        }
        
        // Send response with error handling
        esp_err_t resp_ret = esp_ble_gatts_send_response(gatts_if_param, param->write.conn_id, param->write.trans_id, ESP_GATT_OK, NULL);
        if (resp_ret != ESP_OK) {
            ESP_LOGW(TAG, "Failed to send BLE response: %s", esp_err_to_name(resp_ret));
        }
        break;
        
    case ESP_GATTS_CONNECT_EVT:
        ESP_LOGI(TAG, "ESP_GATTS_CONNECT_EVT, conn_id %d", param->connect.conn_id);
        conn_id = param->connect.conn_id;
        gatts_if = gatts_if_param;
        ble_device_connected = true;
        
        // Reset activity timer on connect
        last_activity_time = xTaskGetTickCount() * portTICK_PERIOD_MS;
        
        // Set maximum MTU for Data Length Extension (DLE)
        esp_err_t mtu_ret = esp_ble_gatt_set_local_mtu(517);
        if (mtu_ret == ESP_OK) {
            ESP_LOGI(TAG, "MTU set to 517 bytes for maximum throughput");
        } else {
            ESP_LOGW(TAG, "Failed to set MTU: %s", esp_err_to_name(mtu_ret));
        }
        
        // Apply BLE timing optimizations after connection
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
void app_main(void)
{
    ESP_LOGI(TAG, "SidekickOS Camera & Audio Streamer Starting...");
    ESP_LOGI(TAG, "======================================");

    // Initialize POSIX stub functions for H.264 library compatibility
    posix_stub_init();

    // Apply advanced CPU performance optimizations
    boost_cpu_performance();

    // Initialize ESP32 task watchdog with longer timeout for initialization
    esp_task_wdt_config_t twdt_config = {
        .timeout_ms = 10000,  // 10 seconds for initialization
        .idle_core_mask = (1 << portNUM_PROCESSORS) - 1,
        .trigger_panic = true
    };
    esp_task_wdt_init(&twdt_config);
    esp_task_wdt_add(NULL);  // Add main task temporarily for initialization

    // Create mutex
    camera_mutex = xSemaphoreCreateMutex();
    if (!camera_mutex) {
        ESP_LOGE(TAG, "Failed to create camera mutex");
        return;
    }

    // Initialize SPIFFS with progress updates
    ESP_LOGI(TAG, "Initializing SPIFFS...");
    esp_task_wdt_reset();  // Reset watchdog before SPIFFS init
    init_spiffs();
    esp_task_wdt_reset();  // Reset watchdog after SPIFFS init
    
    // Initialize camera
    ESP_LOGI(TAG, "Initializing camera...");
    esp_task_wdt_reset();  // Reset watchdog before camera init
    init_camera();
    esp_task_wdt_reset();  // Reset watchdog after camera init
    
    // Initialize microphone
    ESP_LOGI(TAG, "Initializing microphone...");
    esp_task_wdt_reset();  // Reset watchdog before microphone init
    init_microphone();
    esp_task_wdt_reset();  // Reset watchdog after microphone init
    
    // Initialize BLE
    ESP_LOGI(TAG, "Initializing BLE...");
    esp_task_wdt_reset();  // Reset watchdog before BLE init
    init_ble();
    esp_task_wdt_reset();  // Reset watchdog after BLE init
    
    // Create streaming task with large stack for H.264 + BLE operations
    xTaskCreatePinnedToCore(
        streaming_task,
        "streaming_task",
        8192,  // 8KB stack size
        NULL,
        5,     // High priority
        NULL,
        1      // Pin to core 1
    );
    
    // Create audio task with dedicated stack
    xTaskCreatePinnedToCore(
        audio_task,
        "audio_task", 
        4096,  // 4KB stack size
        NULL,
        4,     // Medium priority
        NULL,
        0      // Pin to core 0
    );
    
    ESP_LOGI(TAG, "======================================");
    ESP_LOGI(TAG, "System initialized successfully!");
    ESP_LOGI(TAG, "Device ready for BLE connections...");
    ESP_LOGI(TAG, "Device name: %s", TEST_DEVICE_NAME);
    ESP_LOGI(TAG, "Service UUID: %s", BLE_SERVICE_UUID);
    ESP_LOGI(TAG, "======================================");
    
    // Remove main task from watchdog - it's not doing critical work
    esp_task_wdt_delete(NULL);
    
    // Reconfigure watchdog for normal operation with shorter timeout for worker tasks
    twdt_config.timeout_ms = 5000;  // 5 seconds for worker tasks
    esp_task_wdt_init(&twdt_config);
    
    // Main loop - just keep the task alive, no watchdog needed
    while (true) {
        vTaskDelay(pdMS_TO_TICKS(1000)); // 1 second delay in main loop
    }
}

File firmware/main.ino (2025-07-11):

#include "esp_camera.h"
#include "BLEDevice.h"
#include "BLEServer.h"
#include "BLEUtils.h"
#include "BLE2902.h"
#include "driver/i2s.h"
#include "esp_timer.h"
#include "SPIFFS.h"
#include "esp_task_wdt.h"

// Define camera model to use correct pins
#define CAMERA_MODEL_XIAO_ESP32S3

// Camera pin definitions for XIAO ESP32S3 Sense (from camera_pins.h)
#define PWDN_GPIO_NUM     -1
#define RESET_GPIO_NUM    -1
#define XCLK_GPIO_NUM     10
#define SIOD_GPIO_NUM     40
#define SIOC_GPIO_NUM     39

#define Y9_GPIO_NUM       48
#define Y8_GPIO_NUM       11
#define Y7_GPIO_NUM       12
#define Y6_GPIO_NUM       14
#define Y5_GPIO_NUM       16
#define Y4_GPIO_NUM       18
#define Y3_GPIO_NUM       17
#define Y2_GPIO_NUM       15
#define VSYNC_GPIO_NUM    38
#define HREF_GPIO_NUM     47
#define PCLK_GPIO_NUM     13

#define LED_GPIO_NUM      21

// Microphone I2S pins
#define I2S_WS_PIN         42
#define I2S_SD_PIN         41
#define I2S_SCK_PIN        1

// BLE Configuration
#define BLE_SERVICE_UUID           "12345678-1234-1234-1234-123456789abc"
#define CONTROL_CHAR_UUID          "87654321-4321-4321-4321-cba987654321"
#define STATUS_CHAR_UUID           "11111111-2222-3333-4444-555555555555"
#define IMAGE_CHAR_UUID            "22222222-3333-4444-5555-666666666666"
#define FRAME_CONTROL_CHAR_UUID    "44444444-5555-6666-7777-888888888888"
#define AUDIO_CHAR_UUID            "33333333-4444-5555-6666-777777777777"

// Global variables
BLEServer* pBLEServer = nullptr;
BLECharacteristic* pControlCharacteristic = nullptr;
BLECharacteristic* pStatusCharacteristic = nullptr;
BLECharacteristic* pImageCharacteristic = nullptr;
BLECharacteristic* pFrameControlCharacteristic = nullptr;
BLECharacteristic* pAudioCharacteristic = nullptr;

bool bleDeviceConnected = false;
bool frameStreamingEnabled = false;
bool audioStreamingEnabled = false;
float frameInterval = 1.0f; // seconds between frames (was int)
int imageQuality = 25; // JPEG quality (higher = lower quality)
framesize_t currentFrameSize = FRAMESIZE_QQVGA; // 160x120 for BLE

// Frame streaming variables
unsigned long lastFrameTime = 0;
bool sendingFrame = false;

// Audio variables
const int AUDIO_BUFFER_SIZE = 256;
int16_t audioBuffer[AUDIO_BUFFER_SIZE];
unsigned long lastAudioTime = 0;
const int AUDIO_INTERVAL = 20; // ms between audio packets

// Configuration structure
struct DeviceConfig {
  float frameInterval;
  int imageQuality;
  framesize_t frameSize;
  int audioSampleRate;
  bool motionDetection;
} config;

// Forward declarations
void sendBLEStatus();
void handleControlCommand(String command);
void setFrameSize(int size);
void sendFrame();
void captureHighResImage();
void sendTestImage(); // Added for test pattern
void sendImageViaBLE(uint8_t* imageData, size_t imageSize, BLECharacteristic* characteristic, bool isFrame);
void streamAudio();
void loadConfig();
void saveConfig();
void initCamera();
void initMicrophone();
void initBLE();

// Add cleanup function declaration
void cleanupOnDisconnect();

class MyBLEServerCallbacks: public BLEServerCallbacks {
  void onConnect(BLEServer* pServer) {
    bleDeviceConnected = true;
    Serial.println("BLE Client connected");
    sendBLEStatus();
  }

  void onDisconnect(BLEServer* pServer) {
    Serial.println("BLE Client disconnected");
    
    // Comprehensive cleanup on disconnect
    cleanupOnDisconnect();
    
    // Restart advertising after cleanup
    pServer->startAdvertising();
    Serial.println("Advertising restarted after disconnect");
  }
};

class ControlCallbacks: public BLECharacteristicCallbacks {
  void onWrite(BLECharacteristic *pCharacteristic) {
    String value = pCharacteristic->getValue().c_str();
    if (value.length() > 0) {
      handleControlCommand(value);
    }
  }
};

void setup() {
  Serial.begin(115200);
  Serial.println("ESP32S3 BLE Camera & Audio Streamer Starting...");
  Serial.println("======================================");

  // Initialize ESP32 task watchdog (5s timeout)
  esp_task_wdt_config_t twdt_config = {
    .timeout_ms = 5000, // 5 seconds
    .idle_core_mask = (1 << portNUM_PROCESSORS) - 1, // All cores
    .trigger_panic = true
  };
  esp_task_wdt_init(&twdt_config);
  esp_task_wdt_add(NULL);

  // Initialize SPIFFS
  if (!SPIFFS.begin(true)) {
    Serial.println("SPIFFS Mount Failed");
  }

  // Initialize camera
  Serial.println("Initializing camera...");
  initCamera();
  
  // Initialize microphone
  Serial.println("Initializing microphone...");
  initMicrophone();
  
  // Initialize BLE
  Serial.println("Initializing BLE...");
  initBLE();
  
  // Load configuration
  loadConfig();
  
  Serial.println("======================================");
  Serial.println("System initialized successfully!");
  Serial.println("Device ready for BLE connections...");
  Serial.println("Device name: ESP32S3-Camera");
  Serial.println("Look for this device in your browser's BLE scan");
  Serial.println("======================================");
}

void loop() {
  esp_task_wdt_reset(); // Reset watchdog each loop
  // Print periodic status for debugging
  static unsigned long lastStatusPrint = 0;
  if (millis() - lastStatusPrint > 10000) { // Every 10 seconds
    Serial.printf("Status: BLE %s, Frames %s, Audio %s, Free heap: %d bytes\n", 
                  bleDeviceConnected ? "connected" : "advertising",
                  frameStreamingEnabled ? "streaming" : "stopped",
                  audioStreamingEnabled ? "streaming" : "stopped",
                  ESP.getFreeHeap());
    lastStatusPrint = millis();
  }
  
  // Handle frame streaming
  if (frameStreamingEnabled && bleDeviceConnected && !sendingFrame) {
    unsigned long currentTime = millis();
    if (currentTime - lastFrameTime >= frameInterval * 1000.0f) {
      sendFrame();
      lastFrameTime = currentTime;
    }
  }
  
  // Handle audio streaming
  if (audioStreamingEnabled && bleDeviceConnected) {
    unsigned long currentTime = millis();
    if (currentTime - lastAudioTime >= AUDIO_INTERVAL) {
      streamAudio();
      lastAudioTime = currentTime;
    }
  }
  
  delay(10); // Small delay to prevent watchdog issues (restored from 1)
}
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

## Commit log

2025-07-11 Remove obsolete HTML and test output files
    Deleted several old HTML versions of the BLE frames client and a test output Python file from the archive directory to clean up unused and outdated resources.
2025-07-11 Rename OpenSidekick to SidekickOS across project
    Updated all documentation, code, and configuration files to rename the project from OpenSidekick to SidekickOS. This includes changes to project names, device identifiers, Python package names, and r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
2025-07-13 Add Gemini Live demo and improve camera handling
    Introduces a Gemini Live smart glasses demo with SidekickOS BLE camera integration, including setup documentation, example scripts, and requirements. Enhances ESP32Camera connection logic, device nam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
2025-07-18 Add 3D printable hardware files and update docs
    Added STEP, STL, and 3MF files for the SidekickOS ESP32S3 v1 3D printable mount in the hardware directory. Updated README.md and docs/hardware.md with assembly instructions, hardware renders, and pri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
    [SidekickOS-ESP32S3-v1-print.3mf, SidekickOS-ESP32S3-v1-print.stl, SidekickOS-ESP32S3-v1.step]
2025-08-06 Name fixes
    [SidekickOS-ESP32S3-v1.step]
